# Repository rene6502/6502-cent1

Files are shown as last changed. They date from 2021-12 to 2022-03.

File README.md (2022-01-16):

# 6502-cent1
A single board computer based on the W65C02S CPU.

## Features
- W65C02S running at 1 MHz
- 32K EEPROM
- 32K SRAM
- 2x VIA W65C22
- ACIA W65C51N
- Serial interface via RS232 DB9 or via USB
- Option to power via USB
- Minimal monitor with xmodem upload

## Demo
[This](examples/running_light.mp4) video shows the system in action.
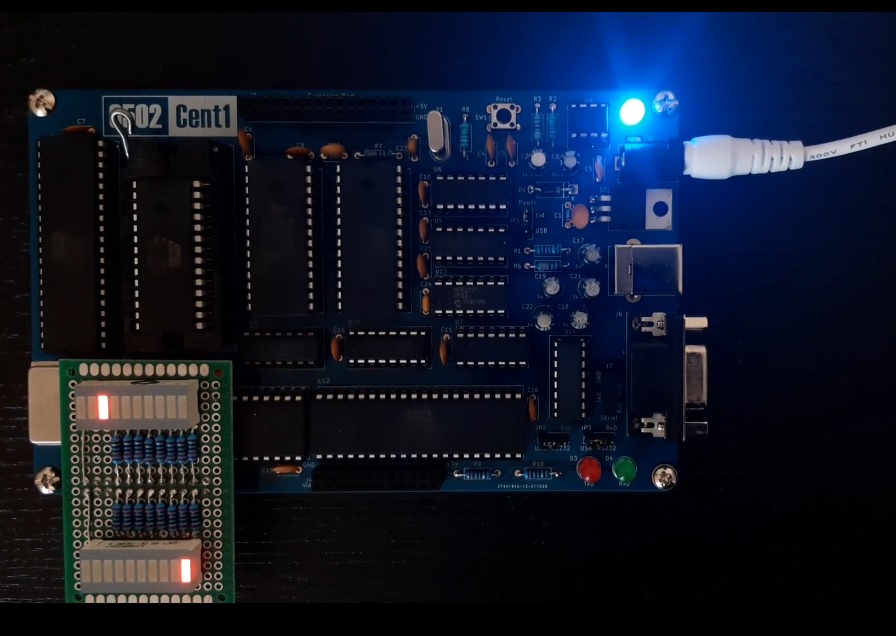
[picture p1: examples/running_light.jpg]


## Schematics and PCB
- [PDF](kicad/schematics.pdf) of schematics
- See the KiCad project in folder [kicad](./kicad)  
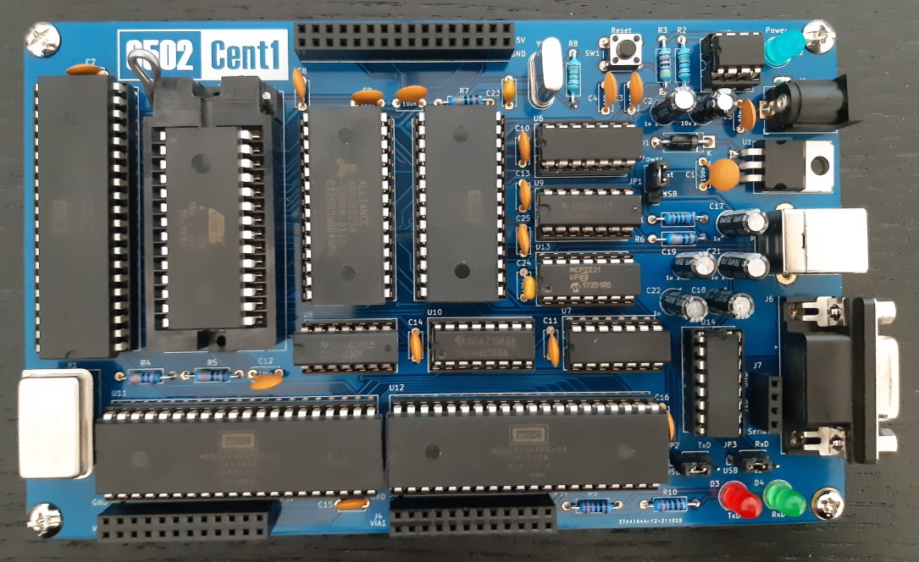
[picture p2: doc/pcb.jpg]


## Jumpers
| JP1 | Function |
| --- | --- |
| Ext | powered from an external power supply (9V DC) connected to J1 |
| USB | powered from USB port |

| JP2 + JP3 | Function |
| --- | --- |
| RS232 | serial connection via classic RS232 DB9 connector |
| USB | serial connection via USB port *) |

*) The USB port implements a standard USB-to-Serial device.  
   It is based on the chip MCP2221 from Microchip Technology and works out of the box with Windows 10/11 and Linux.

## Connectors
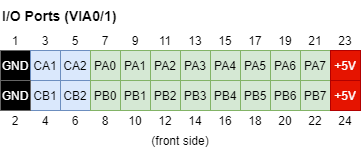
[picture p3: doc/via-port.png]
  
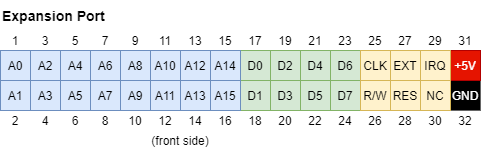
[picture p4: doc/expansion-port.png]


## Software
All assembly programs must be built with [64tass](https://sourceforge.net/projects/tass64).

### Examples
- [running_light](./examples/running_light.asm)  
  outputs cyclic pattern on all VIA ports  
  see [video](examples/running_light.mp4)

- [acia_echo](./examples/acia_echo.asm)  
  echoes received character on serial port

### Enhanced BASIC  
downloads and patches source code with  [this](basic/build.sh) script
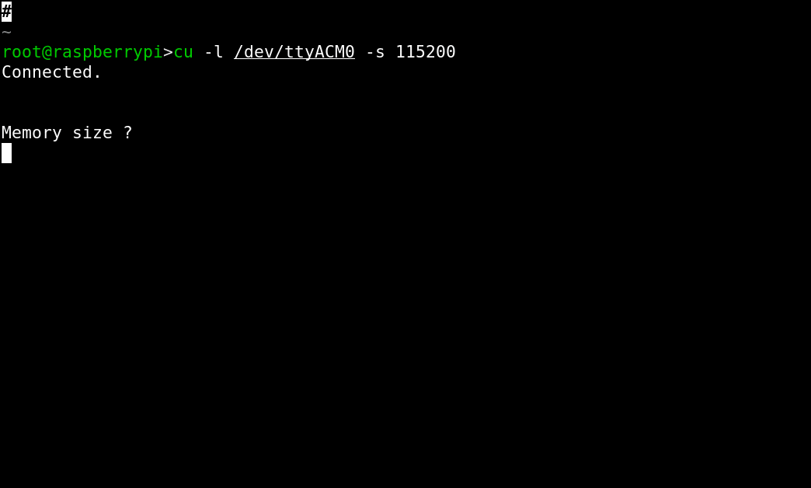
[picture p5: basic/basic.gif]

 
### Monitor
Simple [monitor](monitor/monitor.asm) program to upload and run a program using xmodem protocol.  
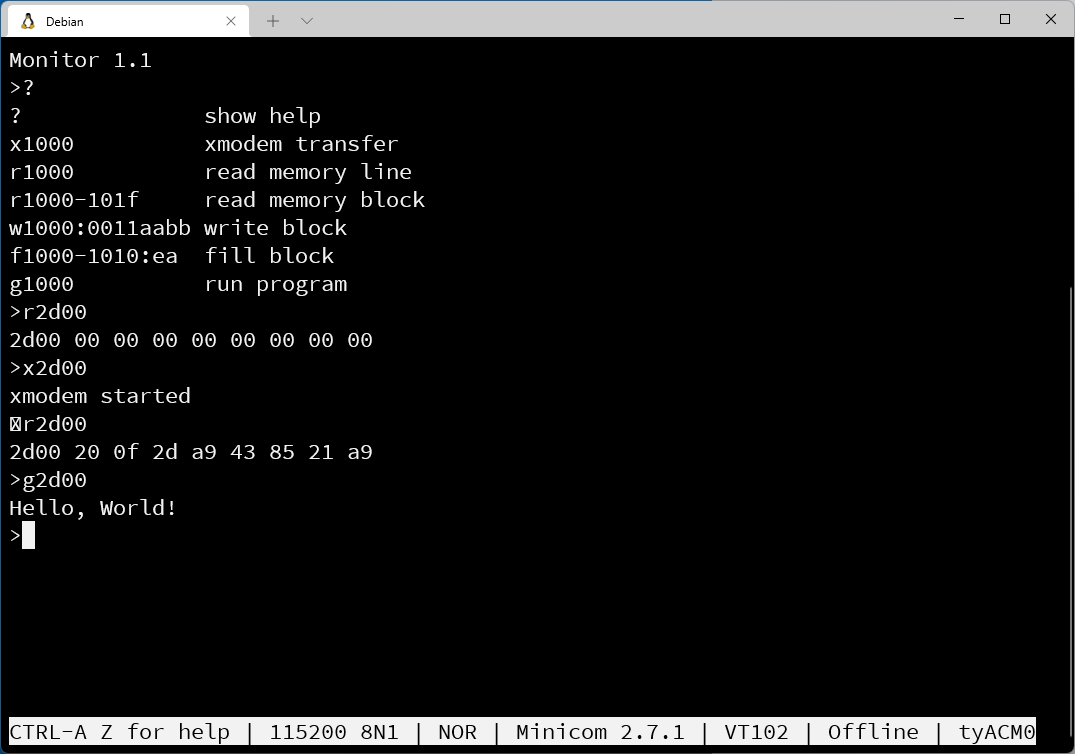
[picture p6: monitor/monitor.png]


## Memory Map
| Address | Device |
| --- | --- |
| $0000-7eff | RAM |
| $7f00-7f0f | VIA0 |
| $7f10-7f1f | VIA1 |
| $7f20-7f2f | ACIA |
| $7f30-7f3f | EXT (expansion port) |
| $7f40-7fff | unused |
| $8000-ffff | ROM |

## Credits
Thanks to Ben Eater’s inspirational [videos](https://www.youtube.com/c/BenEater) and the work published by [Daryl Rictor](https://sbc.rictor.org).

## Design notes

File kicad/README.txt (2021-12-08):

https://github.com/Alarm-Siren/6502-kicad-library

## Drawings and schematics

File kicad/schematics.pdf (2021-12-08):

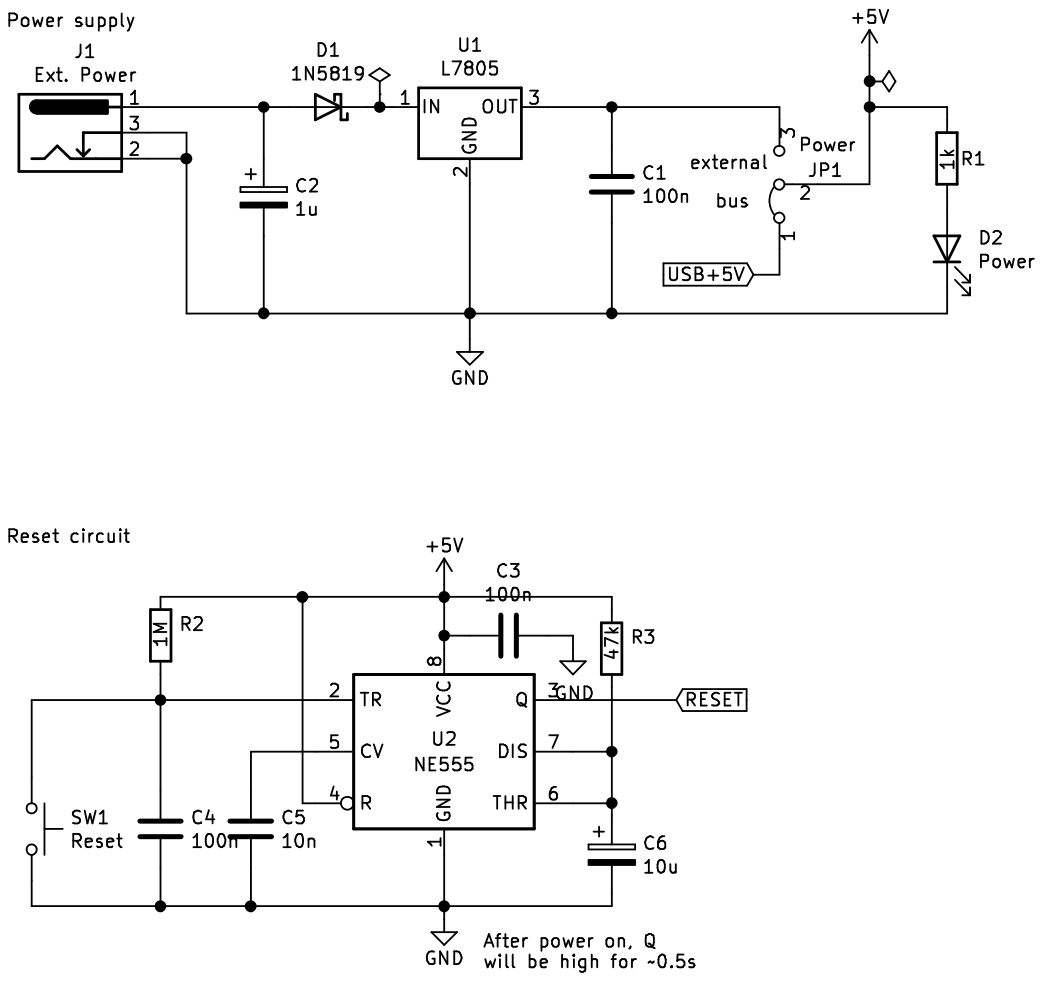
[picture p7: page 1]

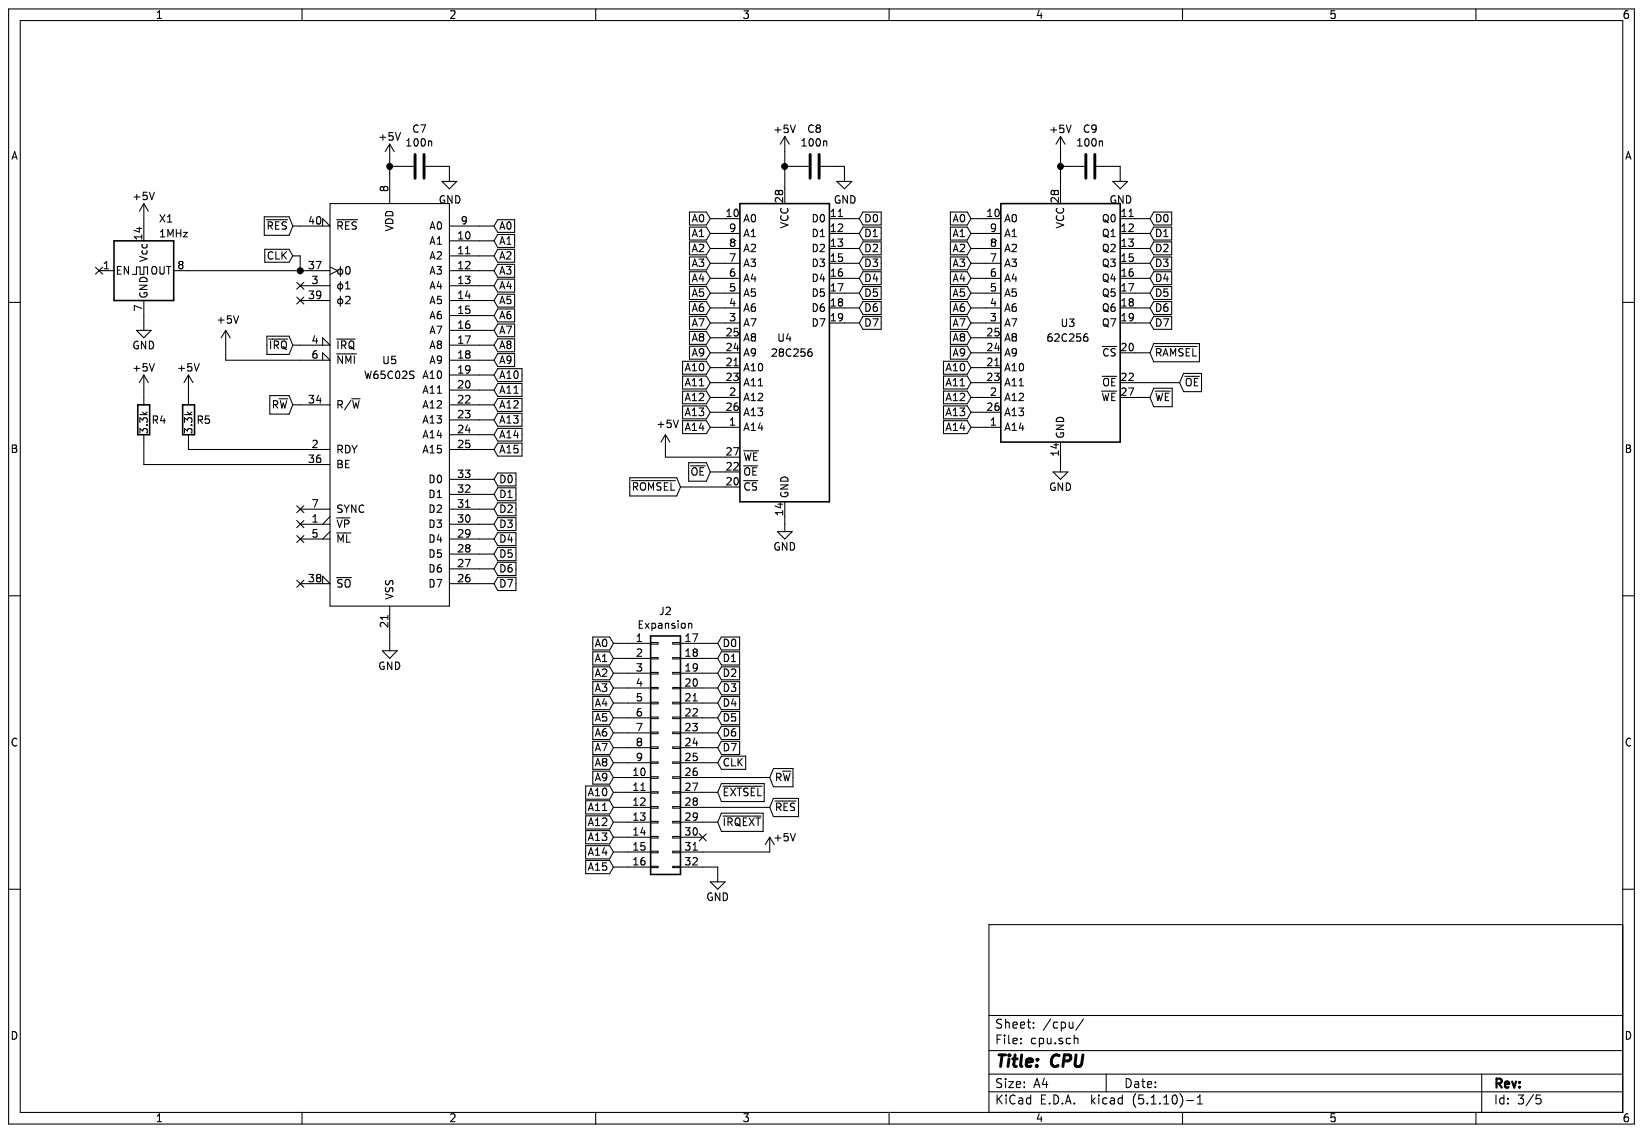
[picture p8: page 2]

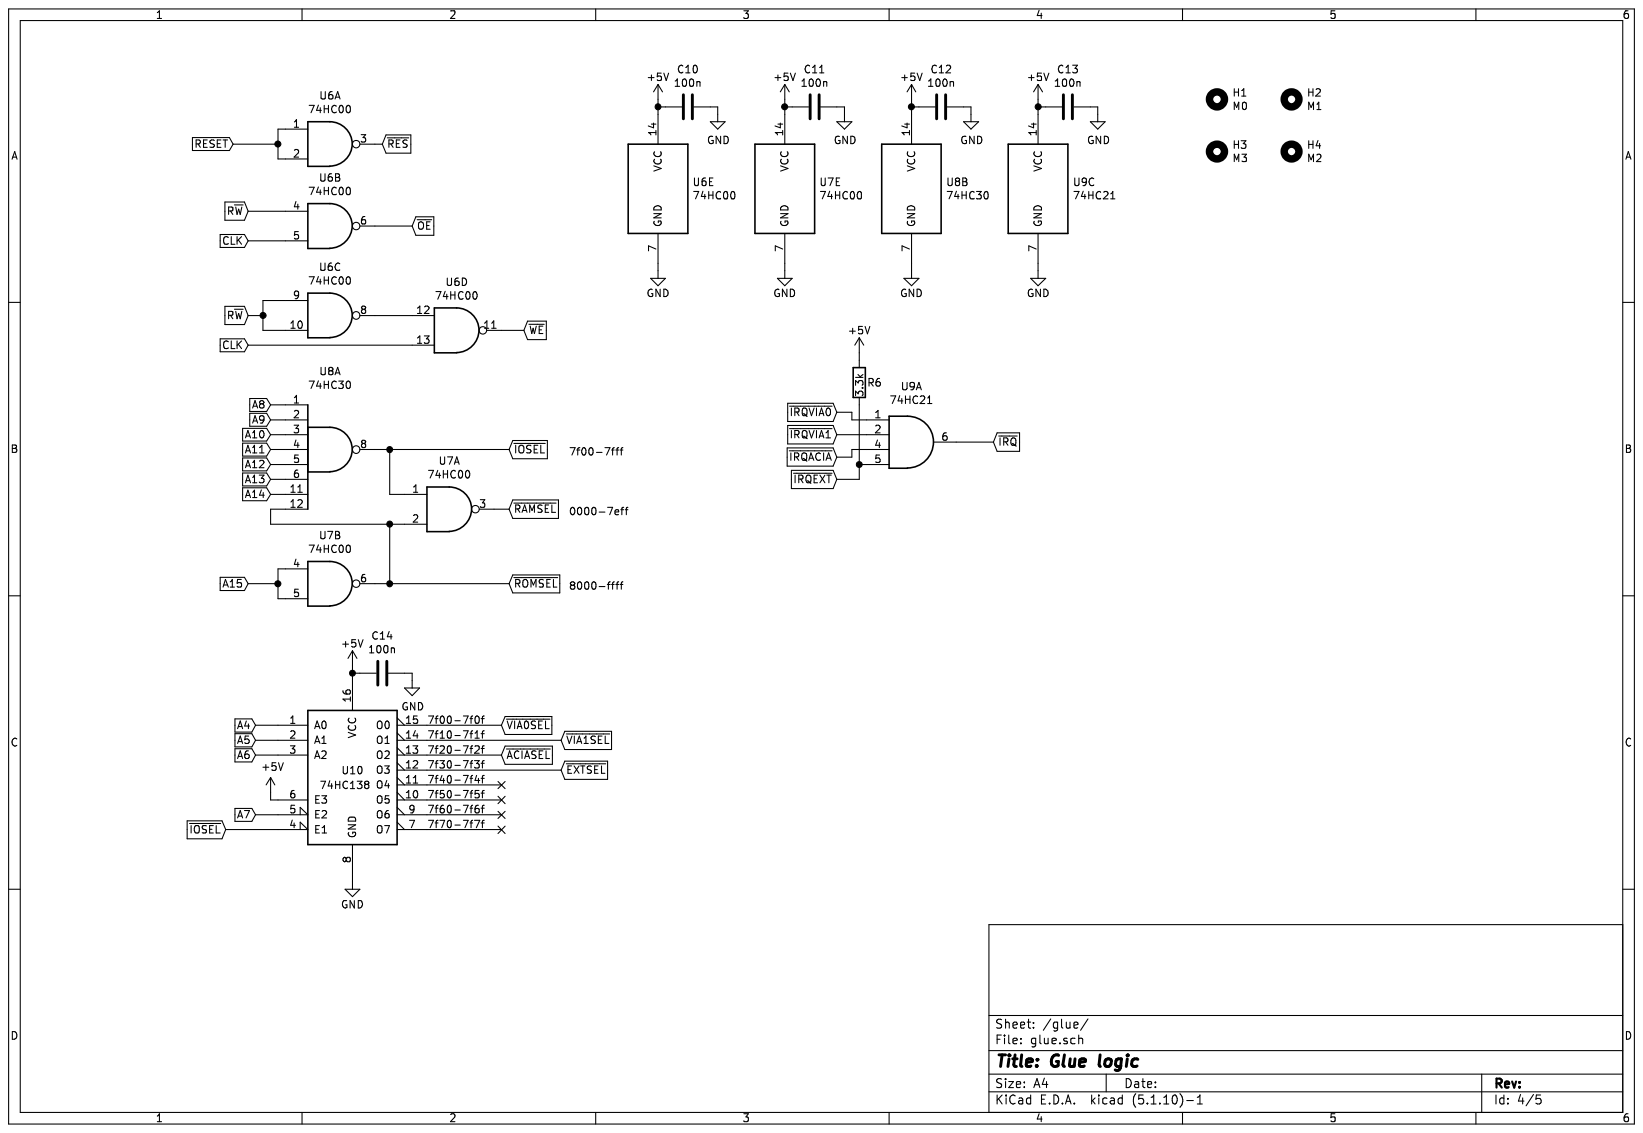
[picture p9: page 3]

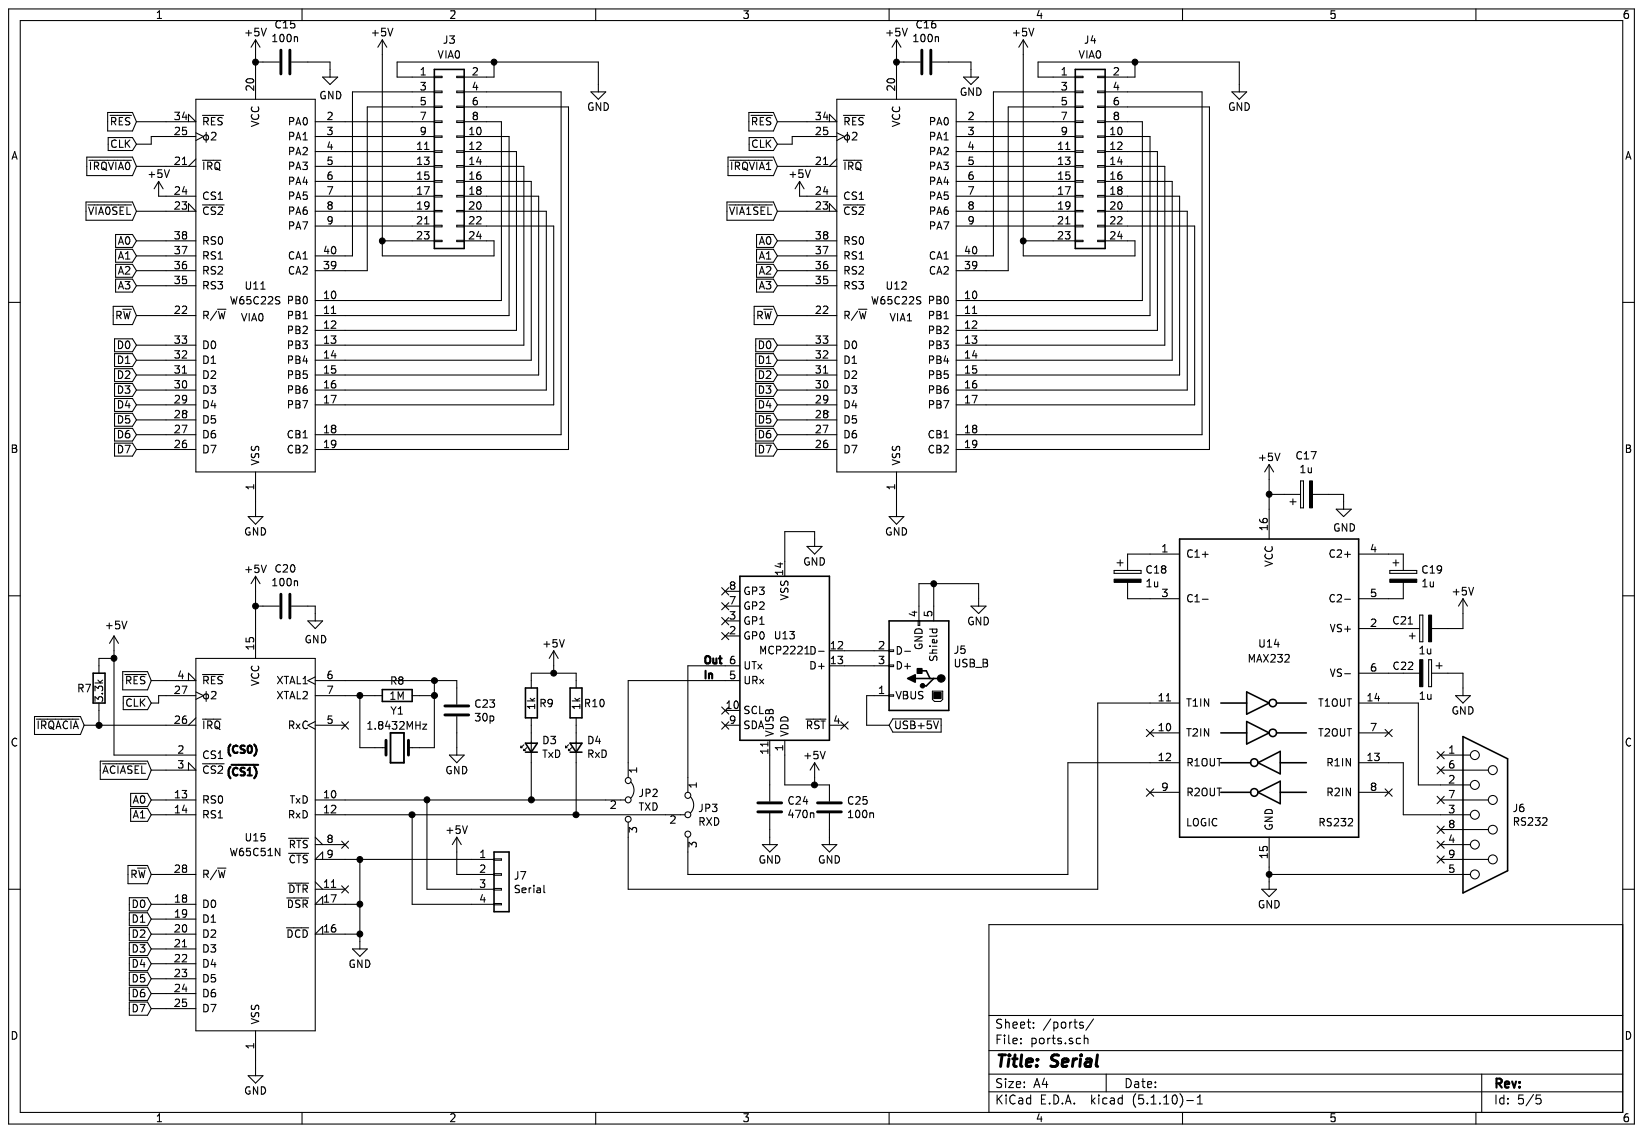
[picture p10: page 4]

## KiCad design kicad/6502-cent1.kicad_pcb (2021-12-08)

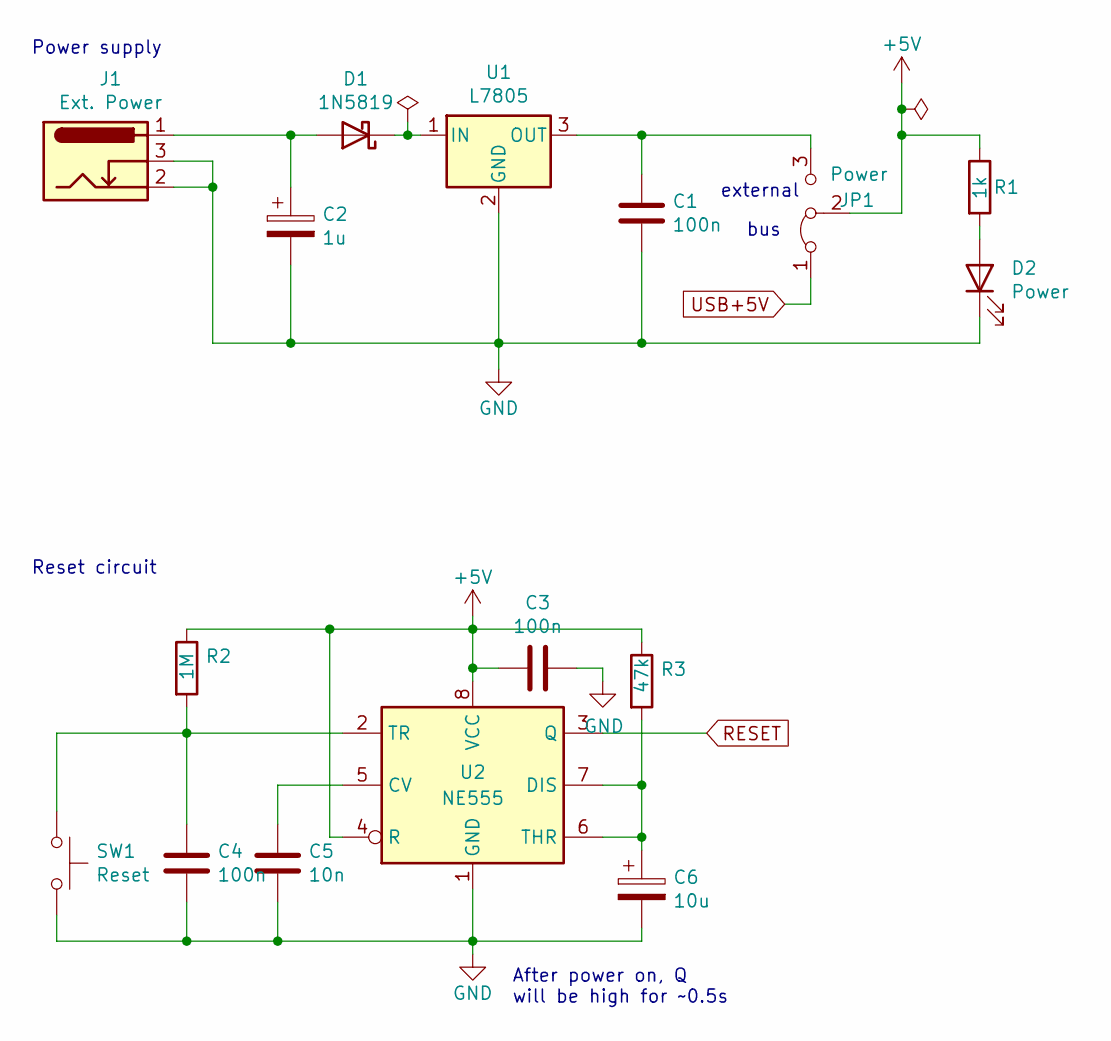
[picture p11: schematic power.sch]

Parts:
C1, C3, C4: 100n; C_Disc_D5.0mm_W2.5mm_P5.00mm
C2: 1u; CP_Radial_D5.0mm_P2.00mm
C5: 10n; C_Disc_D5.0mm_W2.5mm_P5.00mm
C6: 10u; CP_Radial_D5.0mm_P2.00mm
D1: 1N5819; D_DO-15_P10.16mm_Horizontal
D2: Power; LED_D5.0mm
J1: Ext. Power; BarrelJack_Horizontal
JP1: Power; PinHeader_1x03_P2.54mm_Vertical
R1: 1k; R_Axial_DIN0207_L6.3mm_D2.5mm_P10.16mm_Horizontal
R2: 1M; R_Axial_DIN0207_L6.3mm_D2.5mm_P10.16mm_Horizontal
R3: 47k; R_Axial_DIN0207_L6.3mm_D2.5mm_P10.16mm_Horizontal
SW1: Reset; SW_PUSH_6mm_H4.3mm
U1: L7805; TO-220-3_Horizontal_TabDown
U2: NE555; DIP-8_W7.62mm_Socket_LongPads

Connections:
+5V: C3.2, JP1.2 (C), R1.1, R2.1, R3.1, U2.4 (R), U2.8 (VCC); also elsewhere on the board
GND: C1.2, C2.2, C3.1, C4.2, C5.2, C6.2, D2.1 (K), J1.2, J1.3, SW1.2, U1.2 (GND), U2.1 (GND); also elsewhere on the board
unnamed: C1.1, JP1.3 (B), U1.3 (OUT)
unnamed: C2.1, D1.2 (A), J1.1
unnamed: C4.1, R2.2, SW1.1, U2.2 (TR)
unnamed: C5.1, U2.5 (CV)
unnamed: C6.1, R3.2, U2.6 (THR), U2.7 (DIS)
unnamed: D1.1 (K), U1.1 (IN)
unnamed: D2.2 (A), R1.2
RESET: U2.3 (Q); also elsewhere on the board
USB+5V: JP1.1 (A); also elsewhere on the board

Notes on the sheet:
Power supply
Reset circuit
After power on, Q will be high for ~~0.5s
bus
external

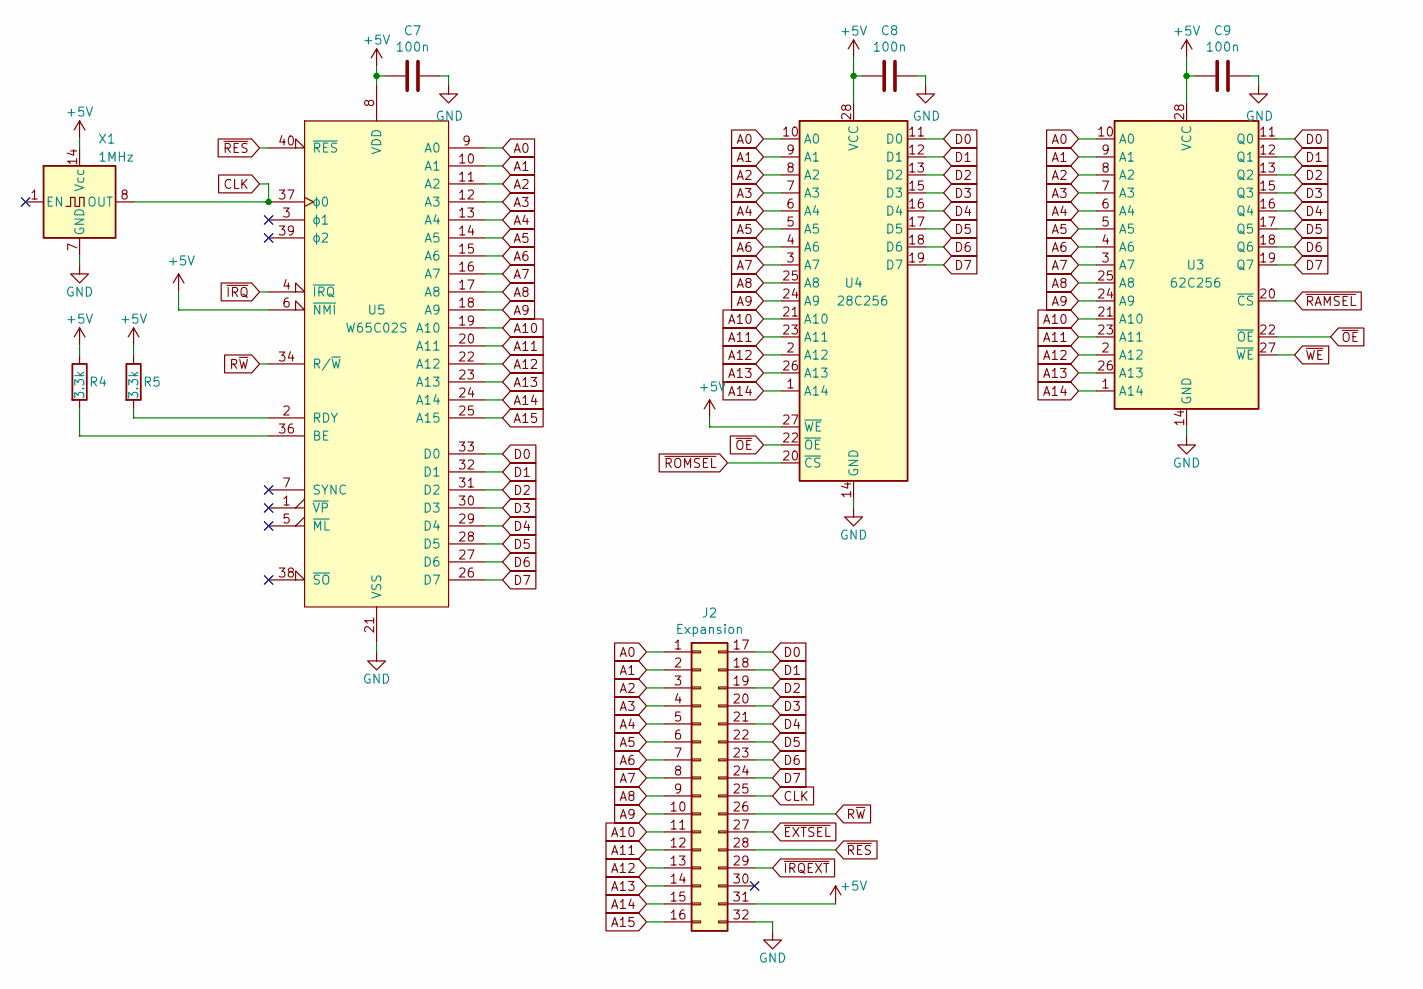
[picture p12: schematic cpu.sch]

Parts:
C7, C8, C9: 100n; C_Disc_D5.0mm_W2.5mm_P5.00mm
J2: Expansion; PinSocket_2x16_P2.54mm_Vertical
R4, R5: 3.3k; R_Axial_DIN0207_L6.3mm_D2.5mm_P10.16mm_Horizontal
U3: 62C256; DIP-28_W15.24mm_Socket_LongPads
U4: 28C256; DIP_Socket-28_W11.9_W12.7_W15.24_W17.78_W18.5_3M_228-1277-0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
U5: W65C02S; DIP-40_W15.24mm_Socket_LongPads
X1: 1MHz; DIP-14_W7.62mm_Socket_LongPads

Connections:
+5V: C7.2, C8.2, C9.2, J2.31, R4.1, R5.1, U3.28 (VCC), U4.27 (~WE), U4.28 (VCC), U5.6 (~NMI), U5.8 (VDD), X1.14 (Vcc); also elsewhere on the board
A0: J2.1, U3.10 (A0), U4.10 (A0), U5.9 (A0); also elsewhere on the board
A1: J2.2, U3.9 (A1), U4.9 (A1), U5.10 (A1); also elsewhere on the board
A2: J2.3, U3.8 (A2), U4.8 (A2), U5.11 (A2); also elsewhere on the board
A3: J2.4, U3.7 (A3), U4.7 (A3), U5.12 (A3); also elsewhere on the board
A4: J2.5, U3.6 (A4), U4.6 (A4), U5.13 (A4); also elsewhere on the board
A5: J2.6, U3.5 (A5), U4.5 (A5), U5.14 (A5); also elsewhere on the board
A6: J2.7, U3.4 (A6), U4.4 (A6), U5.15 (A6); also elsewhere on the board
A7: J2.8, U3.3 (A7), U4.3 (A7), U5.16 (A7); also elsewhere on the board
A8: J2.9, U3.25 (A8), U4.25 (A8), U5.17 (A8); also elsewhere on the board
A9: J2.10, U3.24 (A9), U4.24 (A9), U5.18 (A9); also elsewhere on the board
A10: J2.11, U3.21 (A10), U4.21 (A10), U5.19 (A10); also elsewhere on the board
A11: J2.12, U3.23 (A11), U4.23 (A11), U5.20 (A11); also elsewhere on the board
A12: J2.13, U3.2 (A12), U4.2 (A12), U5.22 (A12); also elsewhere on the board
A13: J2.14, U3.26 (A13), U4.26 (A13), U5.23 (A13); also elsewhere on the board
A14: J2.15, U3.1 (A14), U4.1 (A14), U5.24 (A14); also elsewhere on the board
A15: J2.16, U5.25 (A15); also elsewhere on the board
CLK: J2.25, U5.37 (ϕ0), X1.8 (OUT); also elsewhere on the board
D0: J2.17, U3.11 (Q0), U4.11 (D0), U5.33 (D0); also elsewhere on the board
D1: J2.18, U3.12 (Q1), U4.12 (D1), U5.32 (D1); also elsewhere on the board
D2: J2.19, U3.13 (Q2), U4.13 (D2), U5.31 (D2); also elsewhere on the board
D3: J2.20, U3.15 (Q3), U4.15 (D3), U5.30 (D3); also elsewhere on the board
D4: J2.21, U3.16 (Q4), U4.16 (D4), U5.29 (D4); also elsewhere on the board
D5: J2.22, U3.17 (Q5), U4.17 (D5), U5.28 (D5); also elsewhere on the board
D6: J2.23, U3.18 (Q6), U4.18 (D6), U5.27 (D6); also elsewhere on the board
D7: J2.24, U3.19 (Q7), U4.19 (D7), U5.26 (D7); also elsewhere on the board
GND: C7.1, C8.1, C9.1, J2.32, U3.14 (GND), U4.14 (GND), U5.21 (VSS), X1.7 (GND); also elsewhere on the board
unnamed: R4.2, U5.36 (BE)
unnamed: R5.2, U5.2 (RDY)
R~W: J2.26, U5.34 (R/~W); also elsewhere on the board
~EXTSEL: J2.27; also elsewhere on the board
~IRQ: U5.4 (~IRQ); also elsewhere on the board
~IRQEXT: J2.29; also elsewhere on the board
~OE: U3.22 (~OE), U4.22 (~OE); also elsewhere on the board
~RAMSEL: U3.20 (~CS); also elsewhere on the board
~RES: J2.28, U5.40 (~RES); also elsewhere on the board
~ROMSEL: U4.20 (~CS); also elsewhere on the board
~WE: U3.27 (~WE); also elsewhere on the board

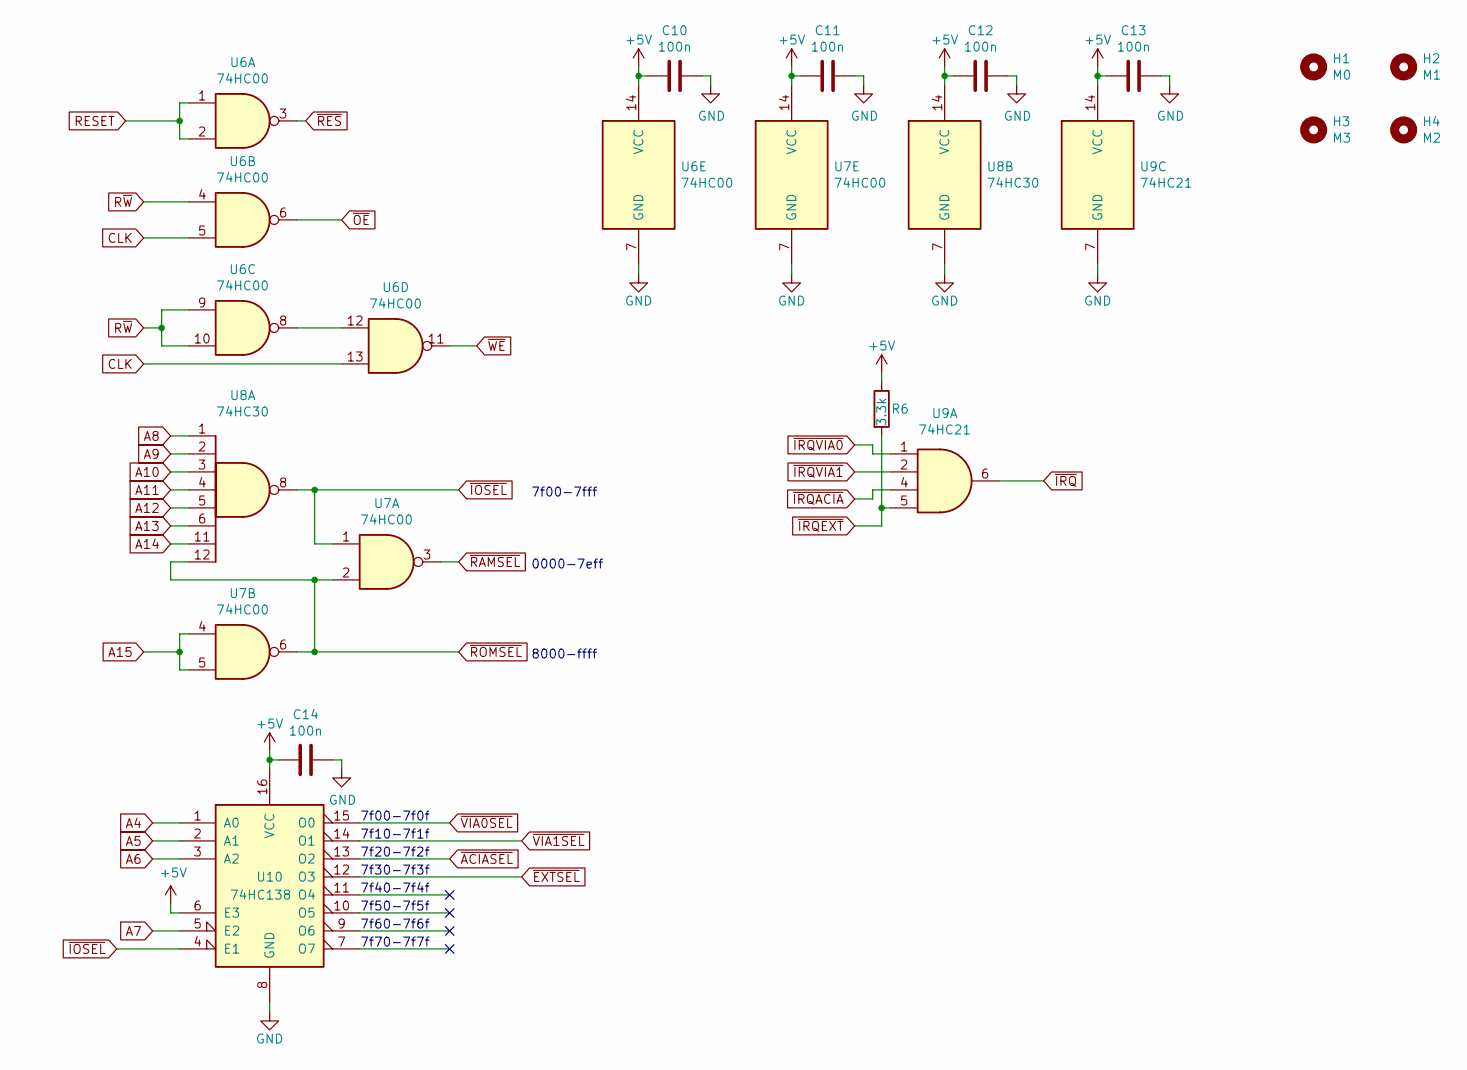
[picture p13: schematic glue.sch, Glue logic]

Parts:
C10, C11, C12, C13, C14: 100n; C_Disc_D5.0mm_W2.5mm_P5.00mm
H1: M0; MountingHole_3.2mm_M3_Pad_Via
H2: M1; MountingHole_3.2mm_M3_Pad_Via
H3: M3; MountingHole_3.2mm_M3_Pad_Via
H4: M2; MountingHole_3.2mm_M3_Pad_Via
R6: 3.3k; R_Axial_DIN0207_L6.3mm_D2.5mm_P10.16mm_Horizontal
U6, U7: 74HC00; DIP-14_W7.62mm_Socket_LongPads
U8: 74HC30; DIP-14_W7.62mm_Socket_LongPads
U9: 74HC21; DIP-14_W7.62mm_Socket_LongPads
U10: 74HC138; DIP-16_W7.62mm_Socket_LongPads

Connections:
+5V: C10.2, C11.2, C12.2, C13.2, C14.2, R6.1, U6.14 (VCC), U7.14 (VCC), U8.14 (VCC), U9.14 (VCC), U10.6 (E3), U10.16 (VCC); also elsewhere on the board
A4: U10.1 (A0); also elsewhere on the board
A5: U10.2 (A1); also elsewhere on the board
A6: U10.3 (A2); also elsewhere on the board
A7: U10.5 (E2); also elsewhere on the board
A8: U8.1; also elsewhere on the board
A9: U8.2; also elsewhere on the board
A10: U8.3; also elsewhere on the board
A11: U8.4; also elsewhere on the board
A12: U8.5; also elsewhere on the board
A13: U8.6; also elsewhere on the board
A14: U8.11; also elsewhere on the board
A15: U7.4, U7.5; also elsewhere on the board
CLK: U6.5, U6.13; also elsewhere on the board
GND: C10.1, C11.1, C12.1, C13.1, C14.1, U6.7 (GND), U7.7 (GND), U8.7 (GND), U9.7 (GND), U10.8 (GND); also elsewhere on the board
unnamed: U6.8, U6.12
RESET: U6.1, U6.2; also elsewhere on the board
R~W: U6.4, U6.9, U6.10; also elsewhere on the board
~ACIASEL: U10.13 (O2); also elsewhere on the board
~EXTSEL: U10.12 (O3); also elsewhere on the board
~IOSEL: U7.1, U8.8, U10.4 (E1)
~IRQ: U9.6; also elsewhere on the board
~IRQACIA: U9.4; also elsewhere on the board
~IRQEXT: R6.2, U9.5; also elsewhere on the board
~IRQVIA0: U9.1; also elsewhere on the board
~IRQVIA1: U9.2; also elsewhere on the board
~OE: U6.6; also elsewhere on the board
~RAMSEL: U7.3; also elsewhere on the board
~RES: U6.3; also elsewhere on the board
~ROMSEL: U7.2, U7.6, U8.12; also elsewhere on the board
~VIA0SEL: U10.15 (O0); also elsewhere on the board
~VIA1SEL: U10.14 (O1); also elsewhere on the board
~WE: U6.11; also elsewhere on the board

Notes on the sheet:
8000-ffff
7f00-7fff
0000-7eff
7f00-7f0f
7f10-7f1f
7f20-7f2f
7f30-7f3f
7f40-7f4f
7f50-7f5f
7f60-7f6f
7f70-7f7f

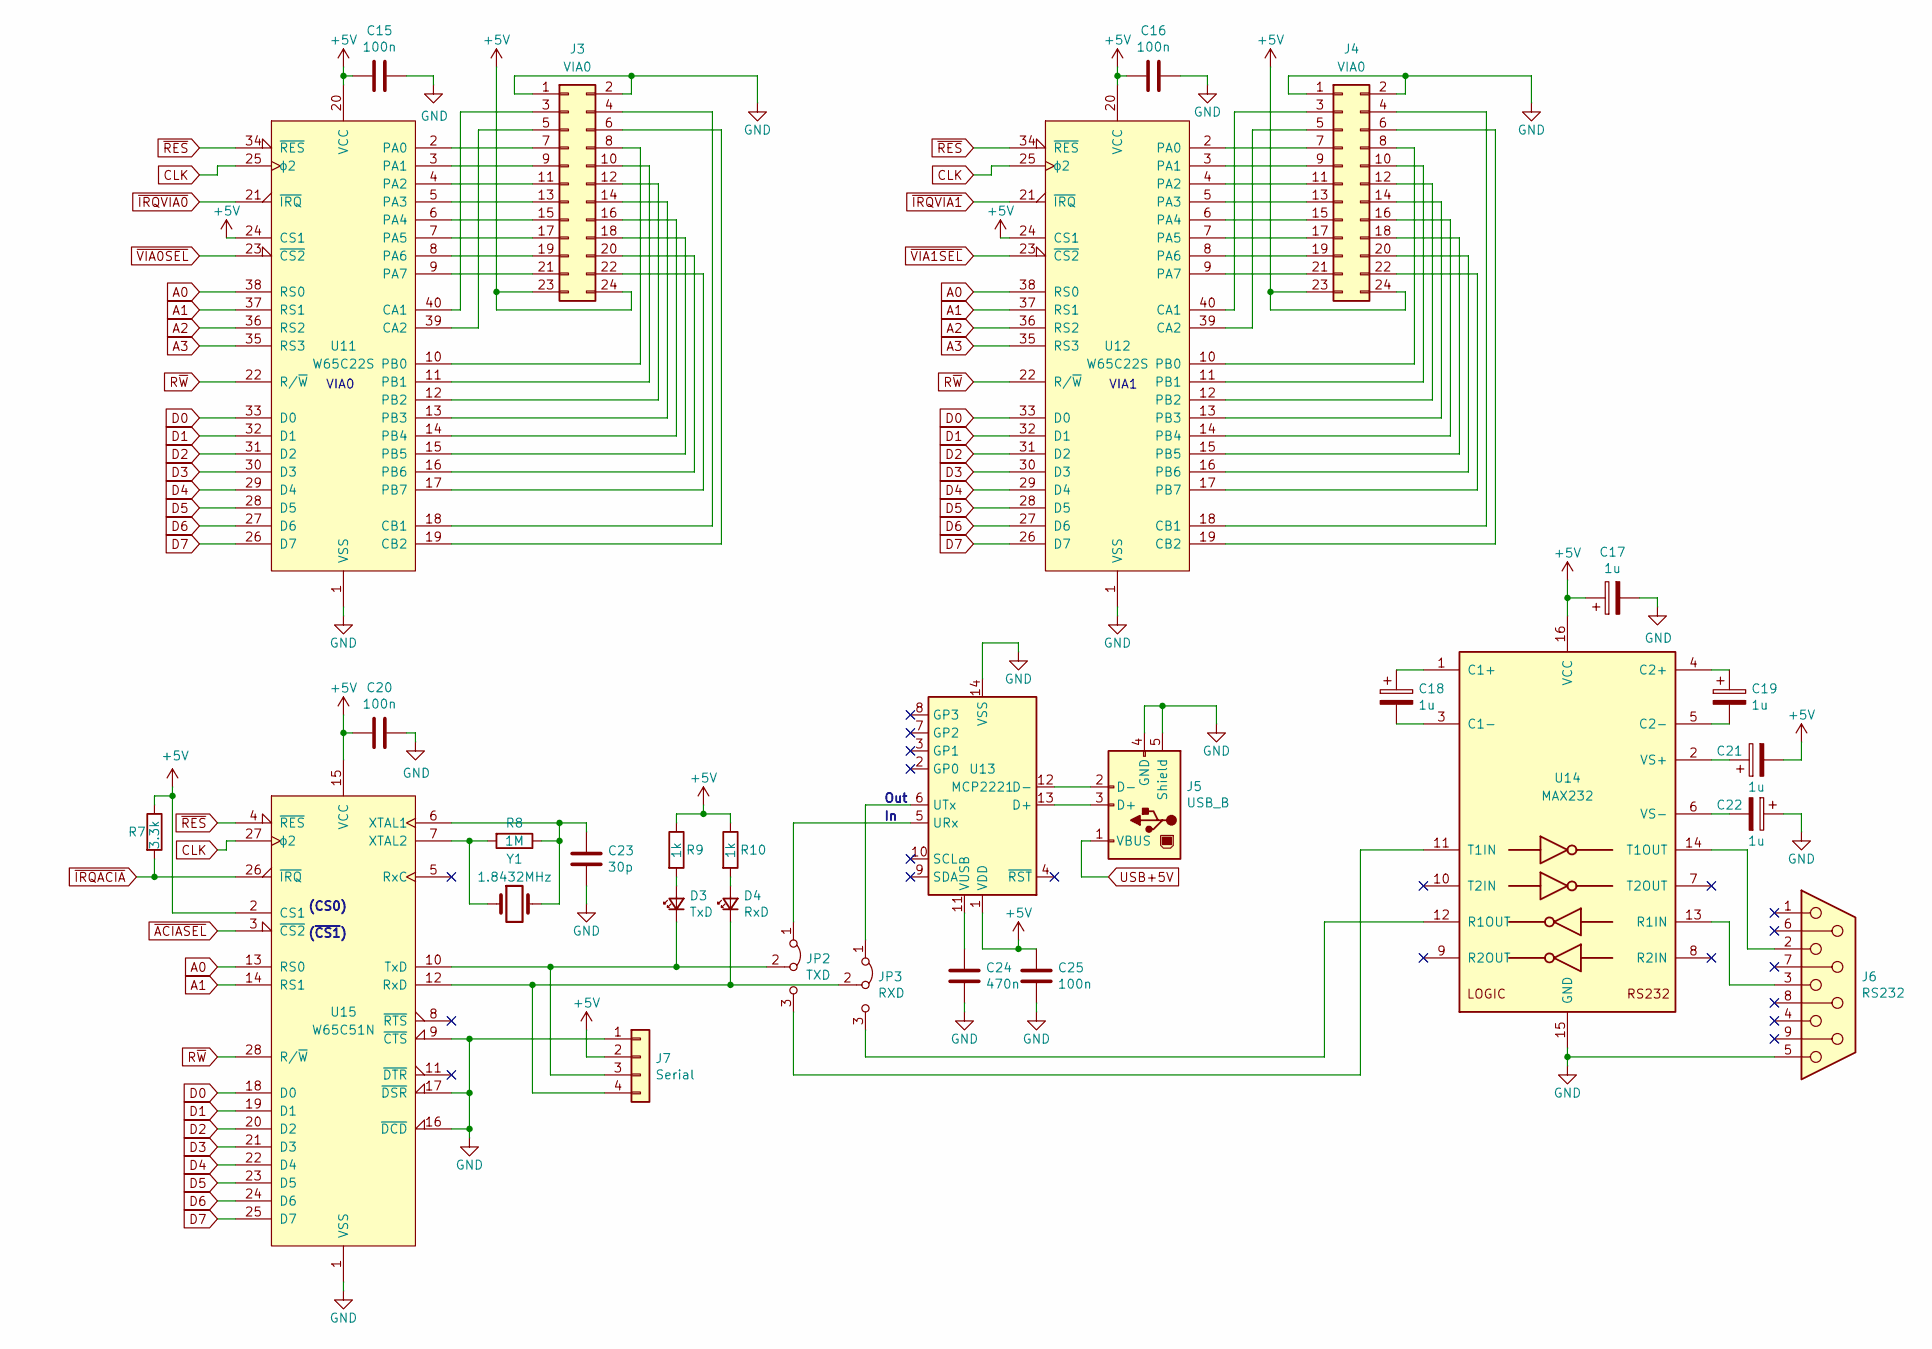
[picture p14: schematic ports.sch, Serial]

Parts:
C15, C16, C20, C25: 100n; C_Disc_D5.0mm_W2.5mm_P5.00mm
C17, C18, C19, C21, C22: 1u; CP_Radial_D5.0mm_P2.00mm
C23: 30p; C_Disc_D5.0mm_W2.5mm_P5.00mm
C24: 470n; C_Disc_D5.0mm_W2.5mm_P5.00mm
D3: TxD; LED_D5.0mm
D4: RxD; LED_D5.0mm
J3, J4: VIA0; PinSocket_2x12_P2.54mm_Vertical
J5: USB_B; USB_B_Lumberg_2411_02_Horizontal
J6: RS232; DSUB-9_Female_Horizontal_P2.77x2.84mm_EdgePinOffset7.70mm_H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
J7: Serial; PinSocket_1x04_P2.54mm_Vertical
JP2: TXD; PinHeader_1x03_P2.54mm_Vertical
JP3: RXD; PinHeader_1x03_P2.54mm_Vertical
R7: 3.3k; R_Axial_DIN0207_L6.3mm_D2.5mm_P10.16mm_Horizontal
R8: 1M; R_Axial_DIN0207_L6.3mm_D2.5mm_P10.16mm_Horizontal
R9, R10: 1k; R_Axial_DIN0207_L6.3mm_D2.5mm_P10.16mm_Horizontal
U11, U12: W65C22S; DIP-40_W15.24mm_Socket_LongPads
U13: MCP2221; DIP-14_W7.62mm_Socket_LongPads
U14: MAX232; DIP-16_W7.62mm_Socket_LongPads
U15: W65C51N; DIP-28_W15.24mm_Socket_LongPads
Y1: 1.8432MHz; Crystal_HC18-U_Vertical

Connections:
+5V: C15.2, C16.2, C17.1, C20.2, C21.2, C25.1, J3.23, J3.24, J4.23, J4.24, J7.2, R7.1, R9.1, R10.1, U11.20 (VCC), U11.24 (CS1), U12.20 (VCC), U12.24 (CS1), U13.1 (VDD), U14.16 (VCC), U15.2 (CS1), U15.15 (VCC); also elsewhere on the board
A0: U11.38 (RS0), U12.38 (RS0), U15.13 (RS0); also elsewhere on the board
A1: U11.37 (RS1), U12.37 (RS1), U15.14 (RS1); also elsewhere on the board
A2: U11.36 (RS2), U12.36 (RS2); also elsewhere on the board
A3: U11.35 (RS3), U12.35 (RS3); also elsewhere on the board
CLK: U11.25 (ϕ2), U12.25 (ϕ2), U15.27 (ϕ2); also elsewhere on the board
D0: U11.33 (D0), U12.33 (D0), U15.18 (D0); also elsewhere on the board
D1: U11.32 (D1), U12.32 (D1), U15.19 (D1); also elsewhere on the board
D2: U11.31 (D2), U12.31 (D2), U15.20 (D2); also elsewhere on the board
D3: U11.30 (D3), U12.30 (D3), U15.21 (D3); also elsewhere on the board
D4: U11.29 (D4), U12.29 (D4), U15.22 (D4); also elsewhere on the board
D5: U11.28 (D5), U12.28 (D5), U15.23 (D5); also elsewhere on the board
D6: U11.27 (D6), U12.27 (D6), U15.24 (D6); also elsewhere on the board
D7: U11.26 (D7), U12.26 (D7), U15.25 (D7); also elsewhere on the board
GND: C15.1, C16.1, C17.2, C20.1, C22.1, C23.2, C24.2, C25.2, J3.1, J3.2, J4.1, J4.2, J5.4 (GND), J5.5 (Shield), J6.5, J7.1, U11.1 (VSS), U12.1 (VSS), U13.14 (VSS), U14.15 (GND), U15.1 (VSS), U15.9 (~CTS), U15.16 (~DCD), U15.17 (~DSR); also elsewhere on the board
unnamed: C18.1, U14.1 (C1+)
unnamed: C18.2, U14.3 (C1-)
unnamed: C19.1, U14.4 (C2+)
unnamed: C19.2, U14.5 (C2-)
unnamed: C21.1, U14.2 (VS+)
unnamed: C22.2, U14.6 (VS-)
unnamed: C23.1, R8.1, U15.6 (XTAL1), Y1.2
unnamed: C24.1, U13.11 (VUSB)
unnamed: D3.1 (K), J7.3, JP2.2 (C), U15.10 (TxD)
unnamed: D3.2 (A), R9.2
unnamed: D4.1 (K), J7.4, JP3.2 (C), U15.12 (RxD)
unnamed: D4.2 (A), R10.2
unnamed: J3.3, U11.40 (CA1)
unnamed: J3.4, U11.18 (CB1)
unnamed: J3.5, U11.39 (CA2)
unnamed: J3.6, U11.19 (CB2)
unnamed: J3.7, U11.2 (PA0)
unnamed: J3.8, U11.10 (PB0)
unnamed: J3.9, U11.3 (PA1)
unnamed: J3.10, U11.11 (PB1)
unnamed: J3.11, U11.4 (PA2)
unnamed: J3.12, U11.12 (PB2)
unnamed: J3.13, U11.5 (PA3)
unnamed: J3.14, U11.13 (PB3)
unnamed: J3.15, U11.6 (PA4)
unnamed: J3.16, U11.14 (PB4)
unnamed: J3.17, U11.7 (PA5)
unnamed: J3.18, U11.15 (PB5)
unnamed: J3.19, U11.8 (PA6)
unnamed: J3.20, U11.16 (PB6)
unnamed: J3.21, U11.9 (PA7)
unnamed: J3.22, U11.17 (PB7)
unnamed: J4.3, U12.40 (CA1)
unnamed: J4.4, U12.18 (CB1)
unnamed: J4.5, U12.39 (CA2)
unnamed: J4.6, U12.19 (CB2)
unnamed: J4.7, U12.2 (PA0)
unnamed: J4.8, U12.10 (PB0)
unnamed: J4.9, U12.3 (PA1)
unnamed: J4.10, U12.11 (PB1)
unnamed: J4.11, U12.4 (PA2)
unnamed: J4.12, U12.12 (PB2)
unnamed: J4.13, U12.5 (PA3)
unnamed: J4.14, U12.13 (PB3)
unnamed: J4.15, U12.6 (PA4)
unnamed: J4.16, U12.14 (PB4)
unnamed: J4.17, U12.7 (PA5)
unnamed: J4.18, U12.15 (PB5)
unnamed: J4.19, U12.8 (PA6)
unnamed: J4.20, U12.16 (PB6)
unnamed: J4.21, U12.9 (PA7)
unnamed: J4.22, U12.17 (PB7)
unnamed: J5.2 (D-), U13.12 (D-)
unnamed: J5.3 (D+), U13.13 (D+)
unnamed: J6.2, U14.14 (T1OUT)
unnamed: J6.3, U14.13 (R1IN)
unnamed: JP2.1 (A), U13.5 (URx)
unnamed: JP2.3 (B), U14.11 (T1IN)
unnamed: JP3.1 (A), U13.6 (UTx)
unnamed: JP3.3 (B), U14.12 (R1OUT)
unnamed: R8.2, U15.7 (XTAL2), Y1.1
R~W: U11.22 (R/~W), U12.22 (R/~W), U15.28 (R/~W); also elsewhere on the board
USB+5V: J5.1 (VBUS); also elsewhere on the board
~ACIASEL: U15.3 (~CS2); also elsewhere on the board
~IRQACIA: R7.2, U15.26 (~IRQ); also elsewhere on the board
~IRQVIA0: U11.21 (~IRQ); also elsewhere on the board
~IRQVIA1: U12.21 (~IRQ); also elsewhere on the board
~RES: U11.34 (~RES), U12.34 (~RES), U15.4 (~RES); also elsewhere on the board
~VIA0SEL: U11.23 (~CS2); also elsewhere on the board
~VIA1SEL: U12.23 (~CS2); also elsewhere on the board

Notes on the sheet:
VIA0
VIA1
(CS0)
(~CS1)
Out

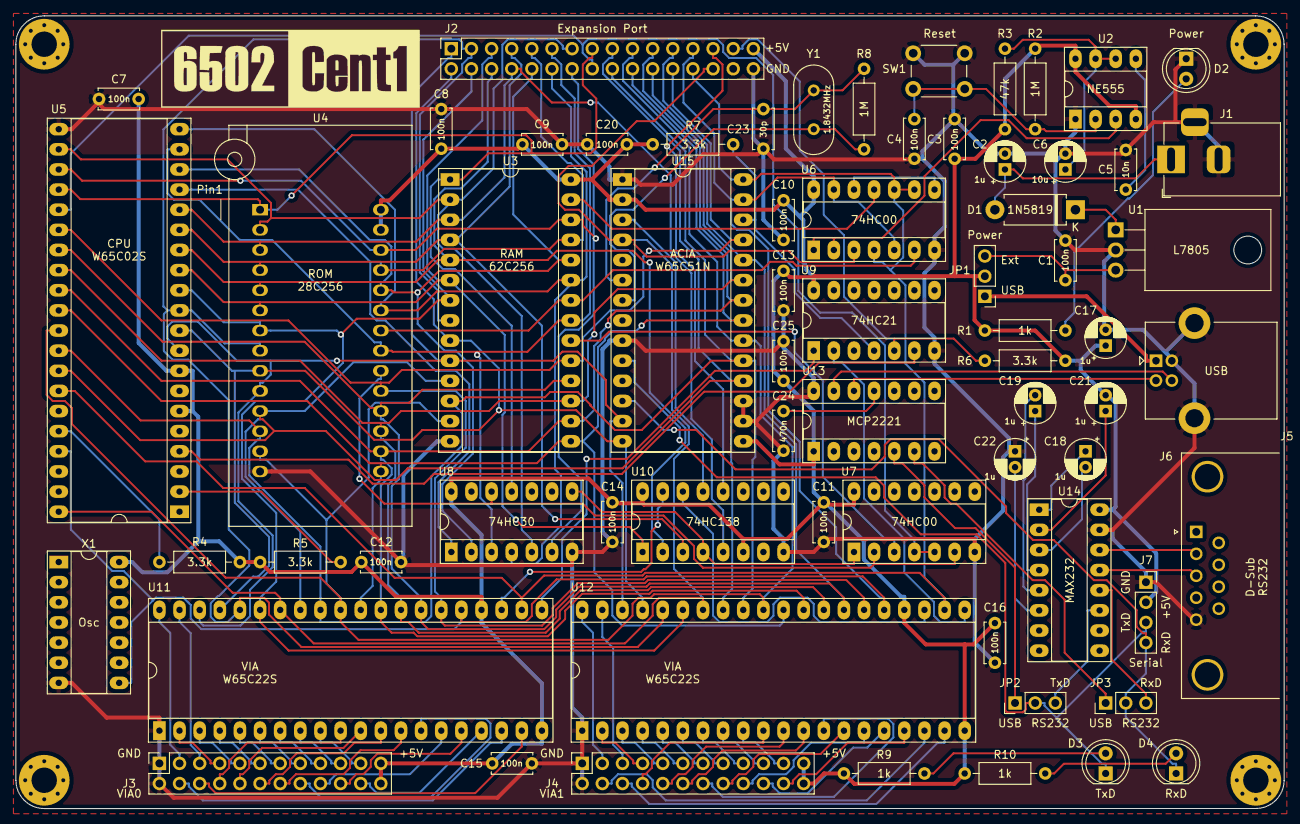
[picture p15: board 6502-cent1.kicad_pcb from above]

Board: 2 copper layers, 160.0 x 100.0 mm, 71 parts (0 on the bottom side), 116 nets.

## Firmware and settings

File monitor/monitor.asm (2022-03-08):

        * = $8000
        
CLOCK_MHZ   = 1         ; // clock frequency in MHz

RAM_END     = $3fff

; 65C51 ACIA
ACIA_BASE   = $7f20
ACIA_DATA   = ACIA_BASE + 0
ACIA_STATUS = ACIA_BASE + 1
ACIA_CMD    = ACIA_BASE + 2
ACIA_CTL    = ACIA_BASE + 3

PROMPT      = '>'
CR          = $0d
LF          = $0a
BS          = $08
ESC         = $1b
LINE_LEN    = 82
XM_BUF_LEN  = 132

XM_ERR_TIMEOUT = 1
XM_ERR_BLOCKNO = 2
XM_ERR_SEQ     = 3
XM_ERR_CKS     = 4

SOH         = $01
EOT         = $04
ACK         = $06
NAK         = $15
CAN         = $18

; zero page
            .virtual $e0
TEMP        .byte ? ; general purpose byte, always assume that subroutines will change this
TEMP_X      .byte ? ; X register backup
TEMP_Y      .byte ? ; Y register backup
MSGL        .byte ? ; message address LSB
MSGH        .byte ? ; message address MSB
ADDR_STARTL .byte ? ; start address
ADDR_STARTH .byte ?
ADDR_ENDL   .byte ? ; end address
ADDR_ENDH   .byte ? ;
            .align 8
XM_ERROR    .byte ? ; xmodem last error
XM_BLK_CNT  .byte ? ; xmodem expected block number
XM_BLK      .byte ? ; xmodem received block number
XM_CKS      .byte ? ; xmodem checksum
XM_ADDRL    .byte ? ; xmodem destination address
XM_ADDRH    .byte ?
XM_COUNT0   .byte ? ; xmodem counter for timeouts
XM_COUNT1   .byte ?
XM_COUNT2   .byte ?
XM_TIMEOUT  .byte ? ; xmodem timeout 
LINE_CNT    .byte ? ; current number of characters in line buffer
LINE_READ   .byte ? ; line buffer read pointer
            .endvirtual
            
            .virtual RAM_END-255
LINE_BUF    .fill LINE_LEN ; size of line buffer
            .align $10
XM_BUFFER   .fill XM_BUF_LEN
END
            .endvirtual

reset:
        cld             ; clear decimal mode
        ldx #$ff        ; initialize stack pointer 
        txs
        
        jsr wait100us
        jsr serial_init
        lda #<MSG_WELCOME
        sta MSGL
        lda #>MSG_WELCOME
        sta MSGH
        jsr write_msg
        
ready:        
        lda #0
        sta LINE_CNT
        lda #PROMPT
        jsr serial_out  ; show prompt

_read_char:
        jsr serial_wait
        jsr serial_out  ; echo
        jsr tolower     ; convert to lower case
        cmp #LF
        beq _read_char   ; ignore line feed
        cmp #CR
        beq newline
        ldy LINE_CNT
        cmp #BS
        bne _store_char
        dey             ; remove last char from buffer
        bmi _reset
        sty LINE_CNT
        jmp _read_char
        
_reset: ldy #0          ; beyond start       
        sty LINE_CNT
        jmp _read_char
        
_store_char:
        cpy #LINE_LEN - 1
        bcs overflow
        sta LINE_BUF,y
        iny
        sty LINE_CNT
        jmp _read_char

newline:
        jsr write_eol
        lda LINE_CNT
        beq ready       ; ignore emty lines
        lda LINE_BUF
        cmp #'?'        ; command "?": help
        bne _chk_x
        jsr cmd_help
        jmp ready
_chk_x:
        cmp #'x'        ; command "x": xmodem
        bne _chk_r
        jsr cmd_xmodem
        jmp ready
_chk_r: 
        cmp #'r'        ; command "r": read memory
        bne _chk_w
        jsr cmd_read
        jmp ready
_chk_w: 
        cmp #'w'        ; command "w": write memory
        bne _chk_f
        jsr cmd_write
        jmp ready
_chk_f: 
        cmp #'f'        ; command "f": fill memory
        bne _chk_g
        jsr cmd_fill
        jmp ready

_chk_g: 
        cmp #'g'        ; command "g": run program
        bne unknown
        jsr cmd_go
        jmp ready

unknown:
        lda #<MSG_UNK_CMD
        sta MSGL
        lda #>MSG_UNK_CMD
        sta MSGH
        jsr write_msg
        jmp ready

overflow:
        lda #<MSG_OVERFLOW
        sta MSGL
        lda #>MSG_OVERFLOW
        sta MSGH
        jsr write_msg
        jmp ready

cmd_help:
        lda #<MSG_HELP
        sta MSGL
        lda #>MSG_HELP
        sta MSGH
        jsr write_msg
        rts
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
